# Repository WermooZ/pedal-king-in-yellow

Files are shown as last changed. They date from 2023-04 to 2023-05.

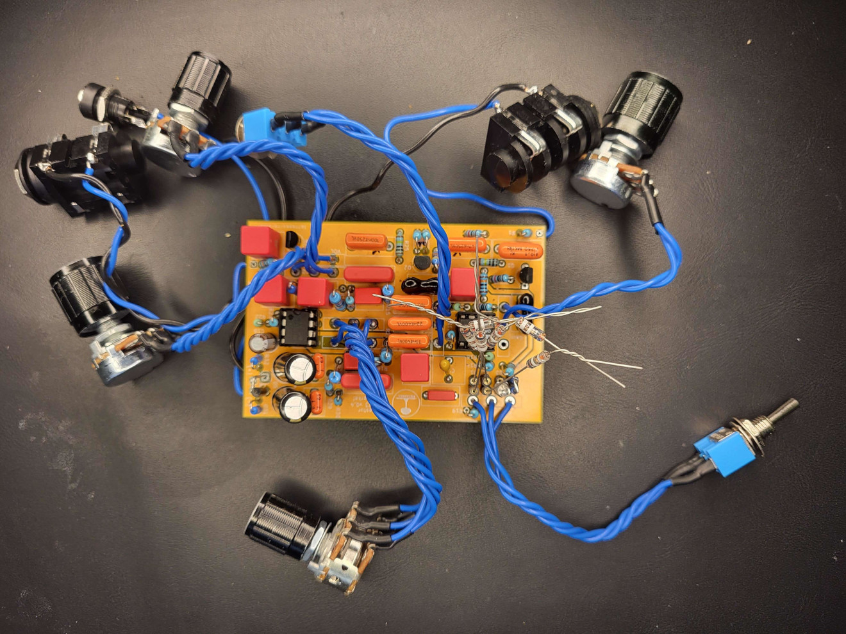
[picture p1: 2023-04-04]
king_in_yelow_assebled.jpg

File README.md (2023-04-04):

# pedal-king-in-yellow

<br />This work is licensed under a <a rel="license" href="http://creativecommons.org/licenses/by-nc-sa/4.0/">Creative Commons Attribution-NonCommercial-ShareAlike 4.0 International License</a>.

Based on the **Exar Super Fuzz SF-02** traced by **VitaliiBobrov** at www.freestompboxes.org

https://www.freestompboxes.org/viewtopic.php?p=293456&hilit=exar#p293456

SF-2 is a fuzz pedal, handmade in Poland in 90s by not existing now Exar Electronix (Janusz Raczyk and Leszek Gruszka).

This version is modified a bit to my taste to improve clarity, tone and noise levels.

Project was assembled and tested - only thing that I messed up is a dual FREQ pot pins -> they are mirrored for one half of pot but it can be fixed by correct wiring so check the schematic first.

Please use Pieczarka logo on pedal enclosure if you want to design own graphics or 'Pieczarka' or 'PCZR' for short.

Project thread on FSB: https://www.freestompboxes.org/viewtopic.php?t=32591

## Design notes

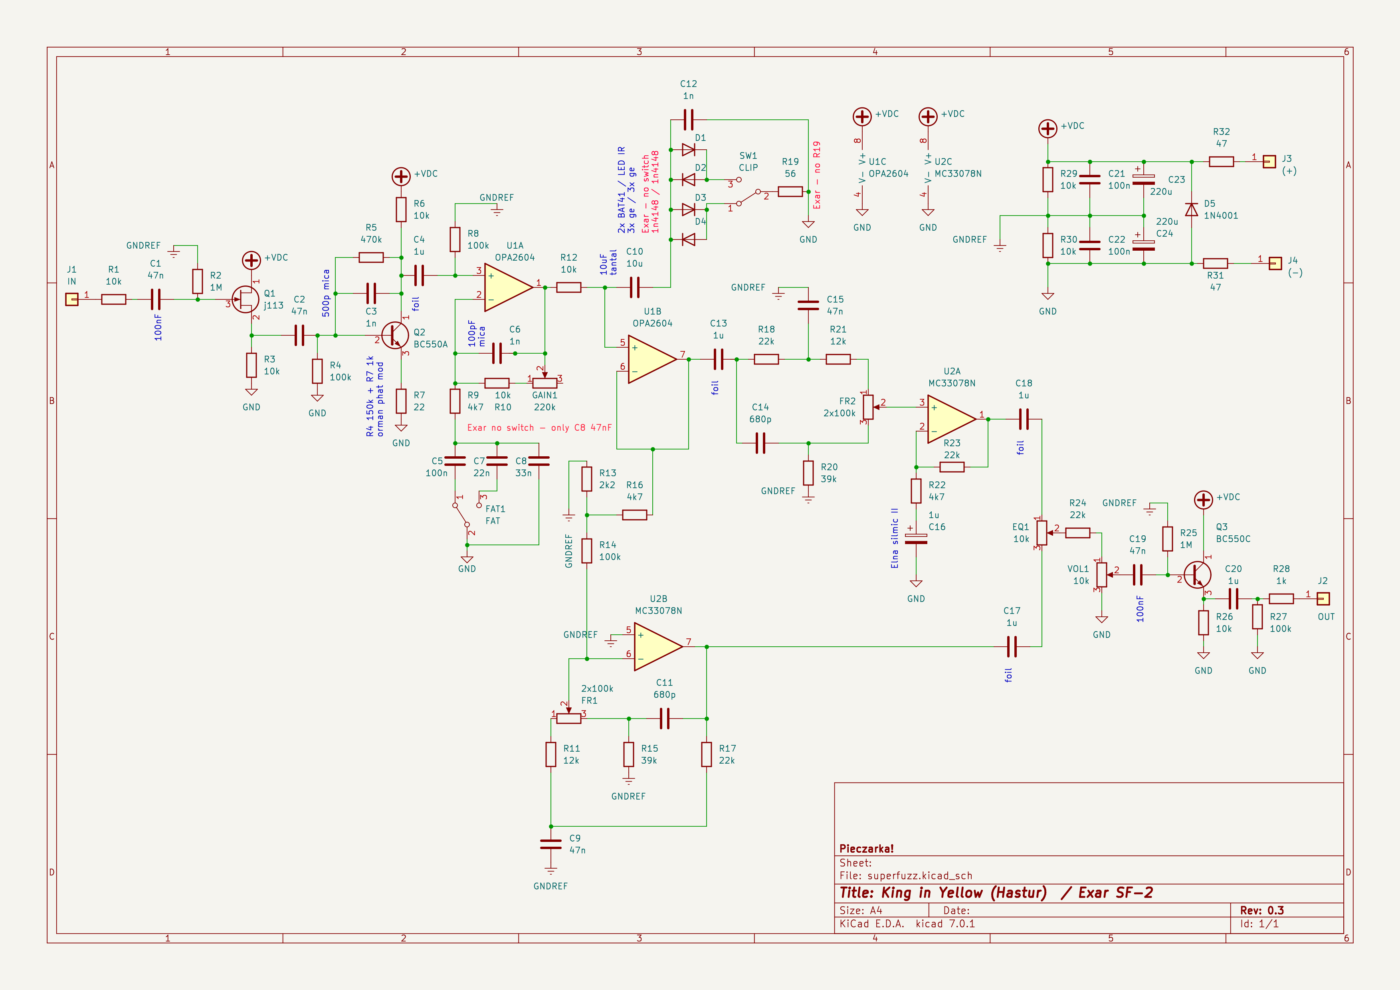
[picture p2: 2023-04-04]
king_in_yellow_schematic.png

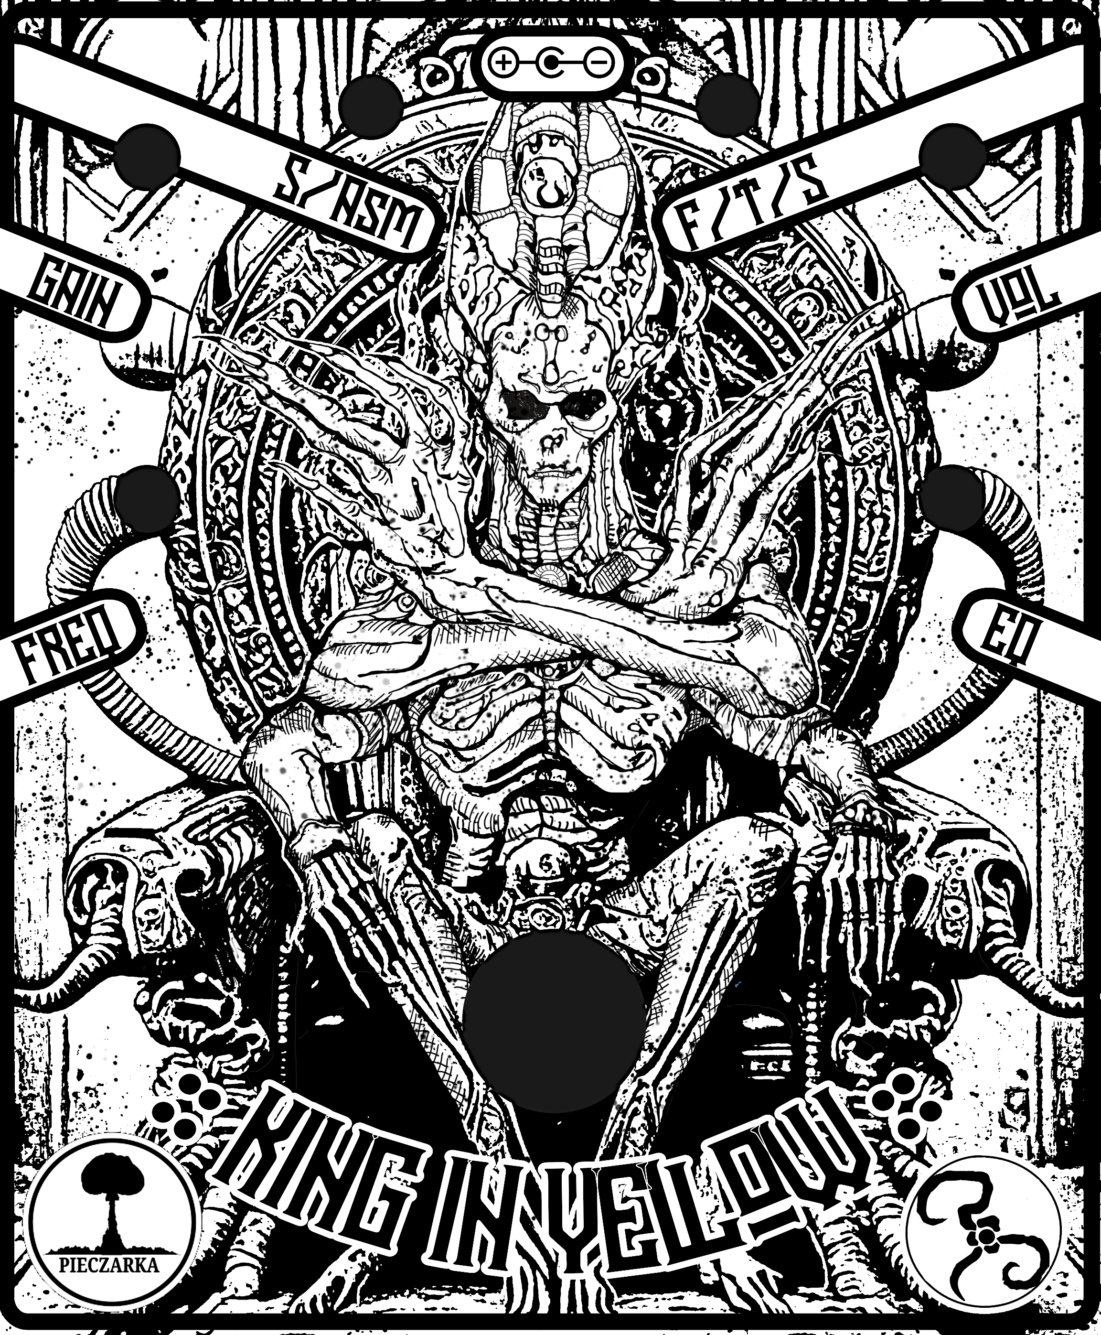
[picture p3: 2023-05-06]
kiy_fx_cover.png

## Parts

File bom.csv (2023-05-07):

Source:
Date: | sob, 28 sty 2023, 21:35:09
Tool: | Eeschema (6.0.10)
Generator: | /usr/share/kicad/plugins/bom_csv_grouped_by_value_with_fp.py
Component Count: | 77
Ref | Qnty | Value | Cmp name | Footprint | Description | Vendor
C1, C2, C9, C15, C19, | 5 | 47n | C | Capacitor_THT:C_Rect_L13.0mm_W5.0mm_P10.00mm_FKS3_FKP3_MKS4 | Unpolarized capacitor
C3, C6, C12, | 3 | 1n | C | Capacitor_THT:C_Rect_L10.0mm_W5.0mm_P5.00mm_P7.50mm | Unpolarized capacitor
C4, C13, C17, C18, C20, | 5 | 1u | C | Capacitor_THT:C_Rect_L7.2mm_W8.5mm_P5.00mm_FKP2_FKP2_MKS2_MKP2 | Unpolarized capacitor
C5, | 1 | 82n | C | Capacitor_THT:C_Rect_L10.0mm_W4.0mm_P7.50mm_MKS4 | Unpolarized capacitor
C7, C8, | 2 | 22n | C | Capacitor_THT:C_Rect_L10.0mm_W4.0mm_P7.50mm_MKS4 | Unpolarized capacitor
C10, | 1 | 10u | C | Capacitor_THT:C_Rect_L7.2mm_W8.5mm_P5.00mm_FKP2_FKP2_MKS2_MKP2 | Unpolarized capacitor
C11, C14, | 2 | 680p | C | Capacitor_THT:C_Rect_L7.2mm_W5.5mm_P5.00mm_FKS2_FKP2_MKS2_MKP2 | Unpolarized capacitor
C16, | 1 | 1u | C_Polarized | Capacitor_THT:CP_Radial_D5.0mm_P2.50mm | Polarized capacitor
C21, C22, | 2 | 100n | C | Capacitor_THT:C_Rect_L7.2mm_W5.5mm_P5.00mm_FKS2_FKP2_MKS2_MKP2 | Unpolarized capacitor
C23, C24, | 2 | 100u | C_Polarized | Capacitor_THT:CP_Radial_D8.0mm_P5.00mm | Polarized capacitor
D1, D2, | 2 | 1N4148 | 1N4148 | Diode_THT:D_DO-35_SOD27_P2.54mm_Vertical_AnodeUp | 100V 0.15A standard switching diode, DO-35
D3, D4, | 2 | Ge | 1N4148 | Diode_THT:D_DO-35_SOD27_P2.54mm_Vertical_AnodeUp | 100V 0.15A standard switching diode, DO-35
D5, | 1 | 1N4001 | 1N4001 | Diode_THT:D_DO-41_SOD81_P3.81mm_Vertical_AnodeUp | 50V 1A General Purpose Rectifier Diode, DO-41
EQ1, | 1 | 10k | R_Potentiometer | varia:potek2 | Potentiometer
FAT1, | 1 | FAT | SW_SPDT | varia:potek2 | Switch, single pole double throw
FR1, | 1 | R_Potentiometer | R_Potentiometer | varia:potek2 | Potentiometer
FR2, | 1 | 100k | R_Potentiometer | varia:potek2 | Potentiometer
GAIN1, | 1 | 220k | R_Potentiometer | varia:potek2 | Potentiometer
J1, | 1 | IN | Conn_01x01 | Connector_Pin:Pin_D0.7mm_L6.5mm_W1.8mm_FlatFork | Generic connector, single row, 01x01, script generated (kicad-library-utils/schlib/autogen/connector/)
J2, | 1 | OUT | Conn_01x01 | Connector_Pin:Pin_D0.7mm_L6.5mm_W1.8mm_FlatFork | Generic connector, single row, 01x01, script generated (kicad-library-utils/schlib/autogen/connector/)
J3, J4, | 2 | Conn_01x01 | Conn_01x01 | Connector_Pin:Pin_D0.7mm_L6.5mm_W1.8mm_FlatFork | Generic connector, single row, 01x01, script generated (kicad-library-utils/schlib/autogen/connector/)
Q1, | 1 | j113 | Q_NJFET_DSG | Package_TO_SOT_THT:TO-92_Inline_Wide | N-JFET transistor, drain/source/gate
Q2, Q3, | 2 | BC550 | BC550 | Package_TO_SOT_THT:TO-92_Inline | 0.1A Ic, 45V Vce, Small Signal NPN Transistor, TO-92
R1, R12, R26, R30, | 4 | 10k | R | Resistor_THT:R_Axial_DIN0204_L3.6mm_D1.6mm_P2.54mm_Vertical | Resistor
R2, R25, | 2 | 1M | R | Resistor_THT:R_Axial_DIN0204_L3.6mm_D1.6mm_P7.62mm_Horizontal | Resistor
R3, R6, R10, R29, | 4 | 10k | R | Resistor_THT:R_Axial_DIN0204_L3.6mm_D1.6mm_P5.08mm_Horizontal | Resistor
R4, R27, | 2 | 100k | R | Resistor_THT:R_Axial_DIN0204_L3.6mm_D1.6mm_P5.08mm_Horizontal | Resistor
R5, | 1 | 470k | R | Resistor_THT:R_Axial_DIN0204_L3.6mm_D1.6mm_P5.08mm_Horizontal | Resistor
R7, | 1 | 22 | R | Resistor_THT:R_Axial_DIN0204_L3.6mm_D1.6mm_P5.08mm_Horizontal | Resistor
R8, | 1 | 100k | R | Resistor_THT:R_Axial_DIN0204_L3.6mm_D1.6mm_P7.62mm_Horizontal | Resistor
R9, | 1 | 4k7 | R | Resistor_THT:R_Axial_DIN0204_L3.6mm_D1.6mm_P5.08mm_Horizontal | Resistor
R11, | 1 | 12k | R | Resistor_THT:R_Axial_DIN0204_L3.6mm_D1.6mm_P5.08mm_Horizontal | Resistor
R13, | 1 | 2k2 | R | Resistor_THT:R_Axial_DIN0204_L3.6mm_D1.6mm_P2.54mm_Vertical | Resistor
R14, | 1 | 100k | R | Resistor_THT:R_Axial_DIN0204_L3.6mm_D1.6mm_P2.54mm_Vertical | Resistor
R15, | 1 | 39k | R | Resistor_THT:R_Axial_DIN0204_L3.6mm_D1.6mm_P2.54mm_Vertical | Resistor
R16, R22, | 2 | 4k7 | R | Resistor_THT:R_Axial_DIN0204_L3.6mm_D1.6mm_P2.54mm_Vertical | Resistor
R17, | 1 | 22k | R | Resistor_THT:R_Axial_DIN0204_L3.6mm_D1.6mm_P5.08mm_Horizontal | Resistor
R18, R23, R24, | 3 | 22k | R | Resistor_THT:R_Axial_DIN0204_L3.6mm_D1.6mm_P2.54mm_Vertical | Resistor
R19, | 1 | 56 | R | Resistor_THT:R_Axial_DIN0204_L3.6mm_D1.6mm_P2.54mm_Vertical | Resistor
R20, | 1 | 39k | R | Resistor_THT:R_Axial_DIN0204_L3.6mm_D1.6mm_P5.08mm_Horizontal | Resistor
R21, | 1 | 12k | R | Resistor_THT:R_Axial_DIN0204_L3.6mm_D1.6mm_P2.54mm_Vertical | Resistor
R28, | 1 | 1k | R | Resistor_THT:R_Axial_DIN0204_L3.6mm_D1.6mm_P5.08mm_Horizontal | Resistor
R31, R32, | 2 | 47 | R | Resistor_THT:R_Axial_DIN0204_L3.6mm_D1.6mm_P2.54mm_Vertical | Resistor
SW1, | 1 | CLIP | SW_SPDT | varia:potek2 | Switch, single pole double throw
U1, U2, | 2 | Opamp_Dual | Opamp_Dual | Package_DIP:DIP-8_W7.62mm_LongPads | Dual operational amplifier
VOL1, | 1 | 10k | R_Potentiometer | varia:potek2 | Potentiometer

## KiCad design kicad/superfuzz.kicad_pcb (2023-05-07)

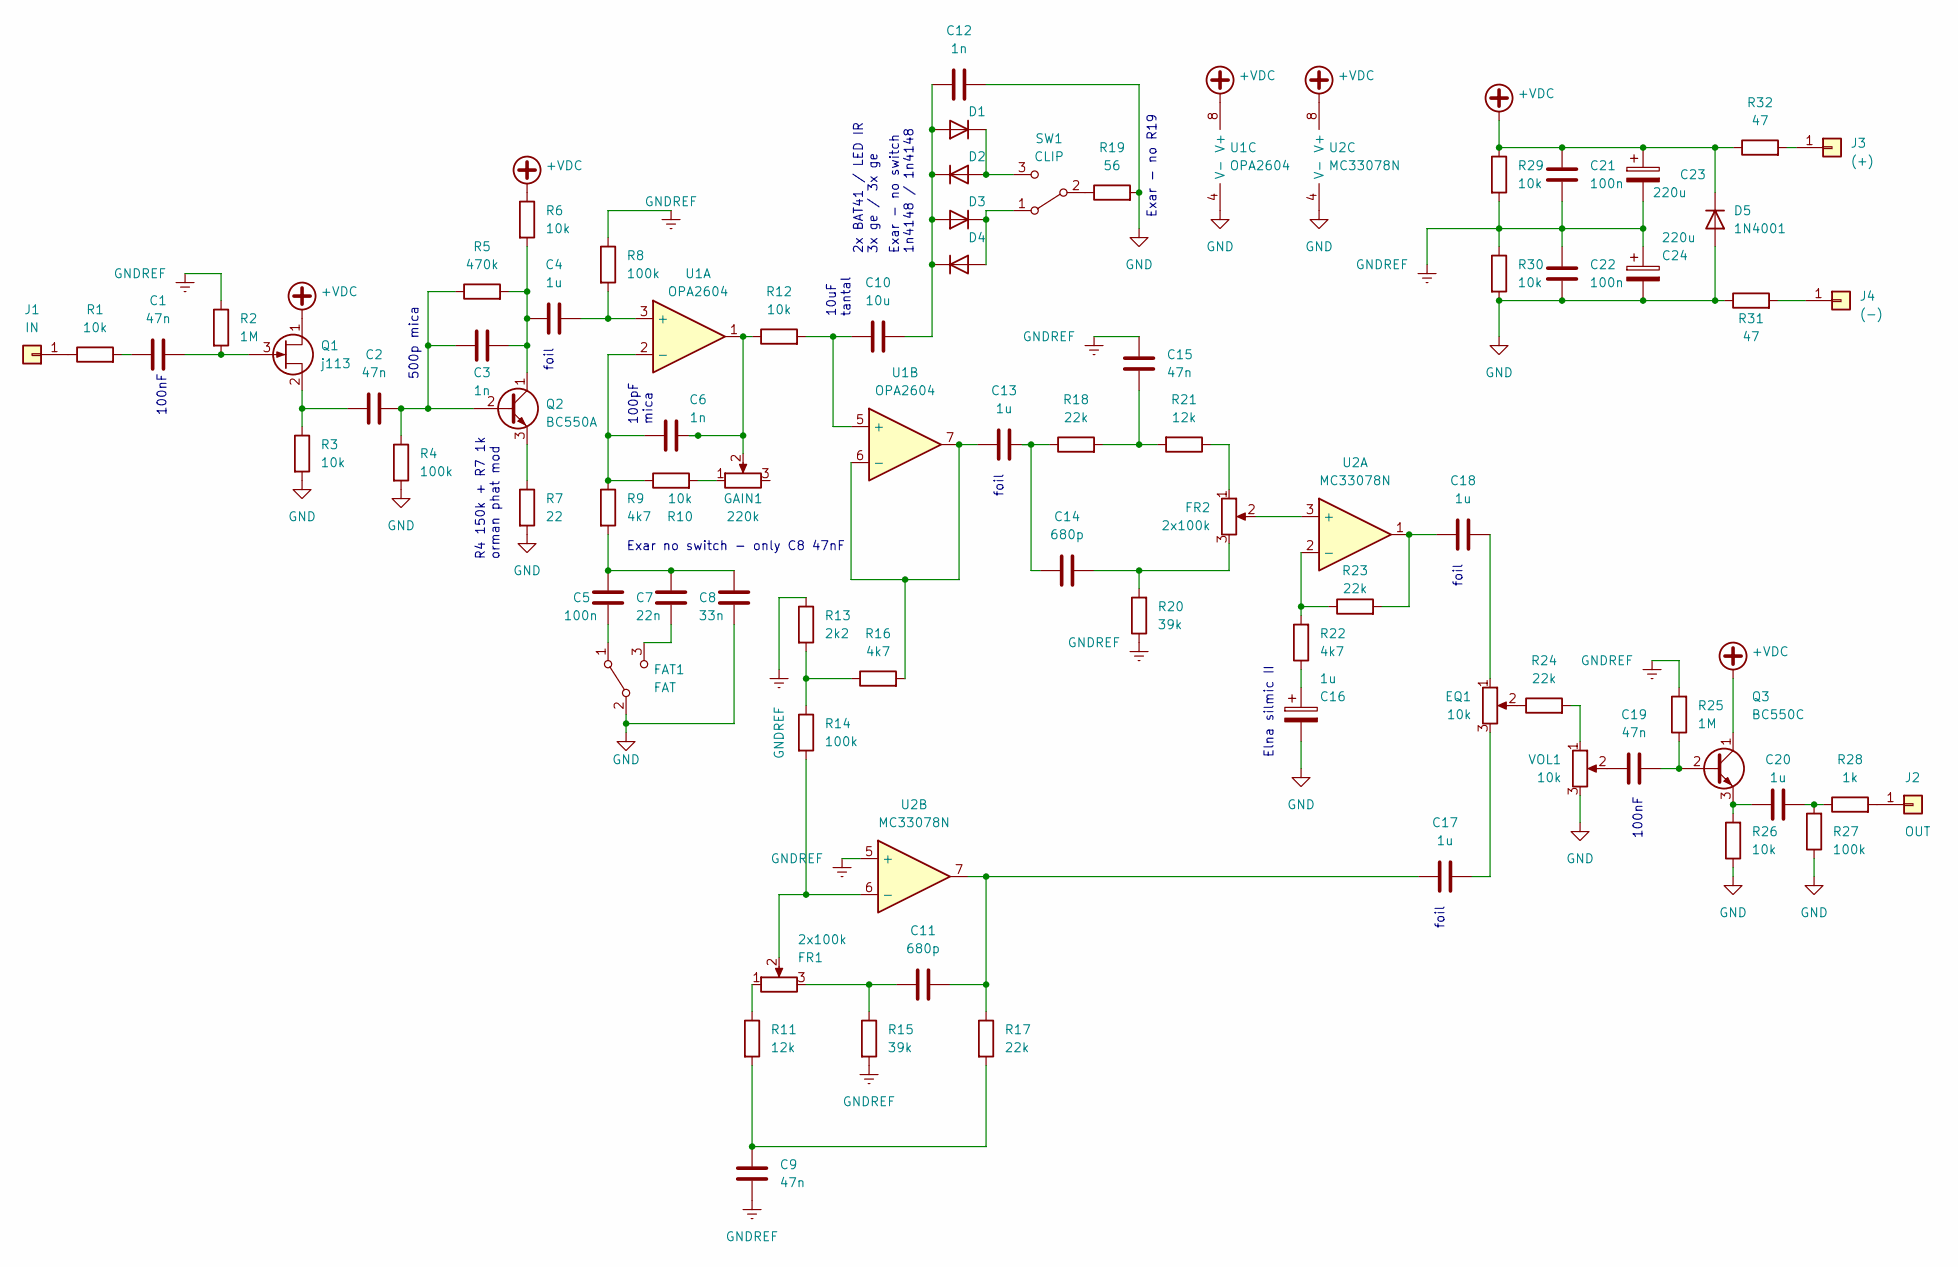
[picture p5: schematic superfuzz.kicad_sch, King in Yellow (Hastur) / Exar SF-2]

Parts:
C1, C2, C9, C15, C19: 47n; C_Rect_L13.0mm_W5.0mm_P10.00mm_FKS3_FKP3_MKS4
C3, C6, C12: 1n; C_Rect_L10.0mm_W5.0mm_P5.00mm_P7.50mm
C4, C13, C17, C18, C20: 1u; C_Rect_L7.2mm_W8.5mm_P5.00mm_FKP2_FKP2_MKS2_MKP2
C5: 100n; C_Rect_L10.0mm_W4.0mm_P7.50mm_MKS4
C7: 22n; C_Rect_L10.0mm_W4.0mm_P7.50mm_MKS4
C8: 33n; C_Rect_L10.0mm_W4.0mm_P7.50mm_MKS4
C10: 10u; C_Rect_L7.2mm_W8.5mm_P5.00mm_FKP2_FKP2_MKS2_MKP2
C11, C14: 680p; C_Rect_L7.2mm_W5.5mm_P5.00mm_FKS2_FKP2_MKS2_MKP2
C16: 1u; CP_Radial_D5.0mm_P2.50mm
C21, C22: 100n; C_Rect_L7.2mm_W5.5mm_P5.00mm_FKS2_FKP2_MKS2_MKP2
C23, C24: 220u; CP_Radial_D8.0mm_P5.00mm
D1, D2: 1N4148; D_DO-35_SOD27_P2.54mm_Vertical_AnodeUp
D3, D4: Ge; D_DO-35_SOD27_P2.54mm_Vertical_AnodeUp
D5: 1N4001; D_DO-41_SOD81_P3.81mm_Vertical_AnodeUp
EQ1: 10k; potek2
FAT1: FAT; potek2
FR1, FR2: 2x100k; potek2
GAIN1: 220k; potek2
J1: IN; Pin_D0.7mm_L6.5mm_W1.8mm_FlatFork
J2: OUT; Pin_D0.7mm_L6.5mm_W1.8mm_FlatFork
J3: (+); Pin_D0.7mm_L6.5mm_W1.8mm_FlatFork
J4: (-); Pin_D0.7mm_L6.5mm_W1.8mm_FlatFork
Q1: j113; TO-92_Inline_Wide
Q2: BC550A; TO-92_Inline
Q3: BC550C; TO-92_Inline
R1, R12, R26, R30: 10k; R_Axial_DIN0204_L3.6mm_D1.6mm_P2.54mm_Vertical
R2, R25: 1M; R_Axial_DIN0204_L3.6mm_D1.6mm_P7.62mm_Horizontal
R3, R6, R10, R29: 10k; R_Axial_DIN0204_L3.6mm_D1.6mm_P5.08mm_Horizontal
R4, R27: 100k; R_Axial_DIN0204_L3.6mm_D1.6mm_P5.08mm_Horizontal
R5: 470k; R_Axial_DIN0204_L3.6mm_D1.6mm_P5.08mm_Horizontal
R7: 22; R_Axial_DIN0204_L3.6mm_D1.6mm_P5.08mm_Horizontal
R8: 100k; R_Axial_DIN0204_L3.6mm_D1.6mm_P7.62mm_Horizontal
R9: 4k7; R_Axial_DIN0204_L3.6mm_D1.6mm_P5.08mm_Horizontal
R11: 12k; R_Axial_DIN0204_L3.6mm_D1.6mm_P5.08mm_Horizontal
R13: 2k2; R_Axial_DIN0204_L3.6mm_D1.6mm_P2.54mm_Vertical
R14: 100k; R_Axial_DIN0204_L3.6mm_D1.6mm_P2.54mm_Vertical
R15: 39k; R_Axial_DIN0204_L3.6mm_D1.6mm_P2.54mm_Vertical
R16, R22: 4k7; R_Axial_DIN0204_L3.6mm_D1.6mm_P2.54mm_Vertical
R17: 22k; R_Axial_DIN0204_L3.6mm_D1.6mm_P5.08mm_Horizontal
R18, R23, R24: 22k; R_Axial_DIN0204_L3.6mm_D1.6mm_P2.54mm_Vertical
R19: 56; R_Axial_DIN0204_L3.6mm_D1.6mm_P2.54mm_Vertical
R20: 39k; R_Axial_DIN0204_L3.6mm_D1.6mm_P5.08mm_Horizontal
R21: 12k; R_Axial_DIN0204_L3.6mm_D1.6mm_P2.54mm_Vertical
R28: 1k; R_Axial_DIN0204_L3.6mm_D1.6mm_P5.08mm_Horizontal
R31, R32: 47; R_Axial_DIN0204_L3.6mm_D1.6mm_P2.54mm_Vertical
SW1: CLIP; potek2
U1: OPA2604; DIP-8_W7.62mm_LongPads
U2: MC33078N; DIP-8_W7.62mm_LongPads
VOL1: 10k; potek2

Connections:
+VDC: C21.1, C23.1, D5.1 (K), Q1.1 (D), Q3.1 (C), R6.1, R29.1, R32.1, U1.8 (V+), U2.8 (V+)
GND: C8.2, C12.2, C16.2, C22.2, C24.2, D5.2 (A), FAT1.2 (B), R3.2, R4.2, R7.2, R19.2, R26.1, R27.1, R30.2, R31.1, U1.4 (V-), U2.4 (V-), VOL1.3
GNDREF: C9.1, C15.2, C21.2, C22.1, C23.2, C24.1, R2.1, R8.1, R13.1, R15.2, R20.1, R25.2, R29.2, R30.1, U2.5 (+)
unnamed: C1.1, R1.2
unnamed: C1.2, Q1.3 (G), R2.2
unnamed: C2.1, Q1.2 (S), R3.1
unnamed: C2.2, C3.1, Q2.2 (B), R4.1, R5.1
unnamed: C3.2, C4.1, Q2.1 (C), R5.2, R6.2
unnamed: C4.2, R8.2, U1.3 (+)
unnamed: C5.1, C7.1, C8.1, R9.2
unnamed: C5.2, FAT1.1 (A)
unnamed: C6.1, R9.1, R10.1, U1.2 (-)
unnamed: C6.2, GAIN1.2, R12.1, U1.1
unnamed: C7.2, FAT1.3 (C)
unnamed: C9.2, R11.2, R17.2
unnamed: C10.1, R12.2, U1.5 (+)
unnamed: C10.2, C12.1, D1.2 (A), D2.1 (K), D3.2 (A), D4.1 (K)
unnamed: C11.1, FR1.3, R15.1
unnamed: C11.2, C17.1, R17.1, U2.7
unnamed: C13.1, R16.2, U1.6 (-), U1.7
unnamed: C13.2, C14.1, R18.1
unnamed: C14.2, FR2.3, R20.2
unnamed: C15.1, R18.2, R21.2
unnamed: C16.1, R22.1
unnamed: C17.2, EQ1.3
unnamed: C18.1, R23.2, U2.1
unnamed: C18.2, EQ1.1
unnamed: C19.1, VOL1.2
unnamed: C19.2, Q3.2 (B), R25.1
unnamed: C20.1, Q3.3 (E), R26.2
unnamed: C20.2, R27.2, R28.1
unnamed: D1.1 (K), D2.2 (A), SW1.3 (C)
unnamed: D3.1 (K), D4.2 (A), SW1.1 (A)
unnamed: EQ1.2, R24.1
unnamed: FR1.1, R11.1
unnamed: FR1.2, R14.2, U2.6 (-)
unnamed: FR2.1, R21.1
unnamed: FR2.2, U2.3 (+)
unnamed: GAIN1.1, R10.2
unnamed: J1.1, R1.1
unnamed: J2.1, R28.2
unnamed: J3.1, R32.2
unnamed: J4.1, R31.2
unnamed: Q2.3 (E), R7.1
unnamed: R13.2, R14.1, R16.1
unnamed: R19.1, SW1.2 (B)
unnamed: R22.2, R23.1, U2.2 (-)
unnamed: R24.2, VOL1.1

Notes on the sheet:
Exar - no switch 1n4148 / 1n4148
100nF
Exar no switch - only C8 47nF
500p mica
foil
10uF tantal
Elna silmic II
Exar - no R19
100pF mica
R4 150k + R7 1k orman phat mod
2x BAT41 / LED IR 3x ge / 3x ge

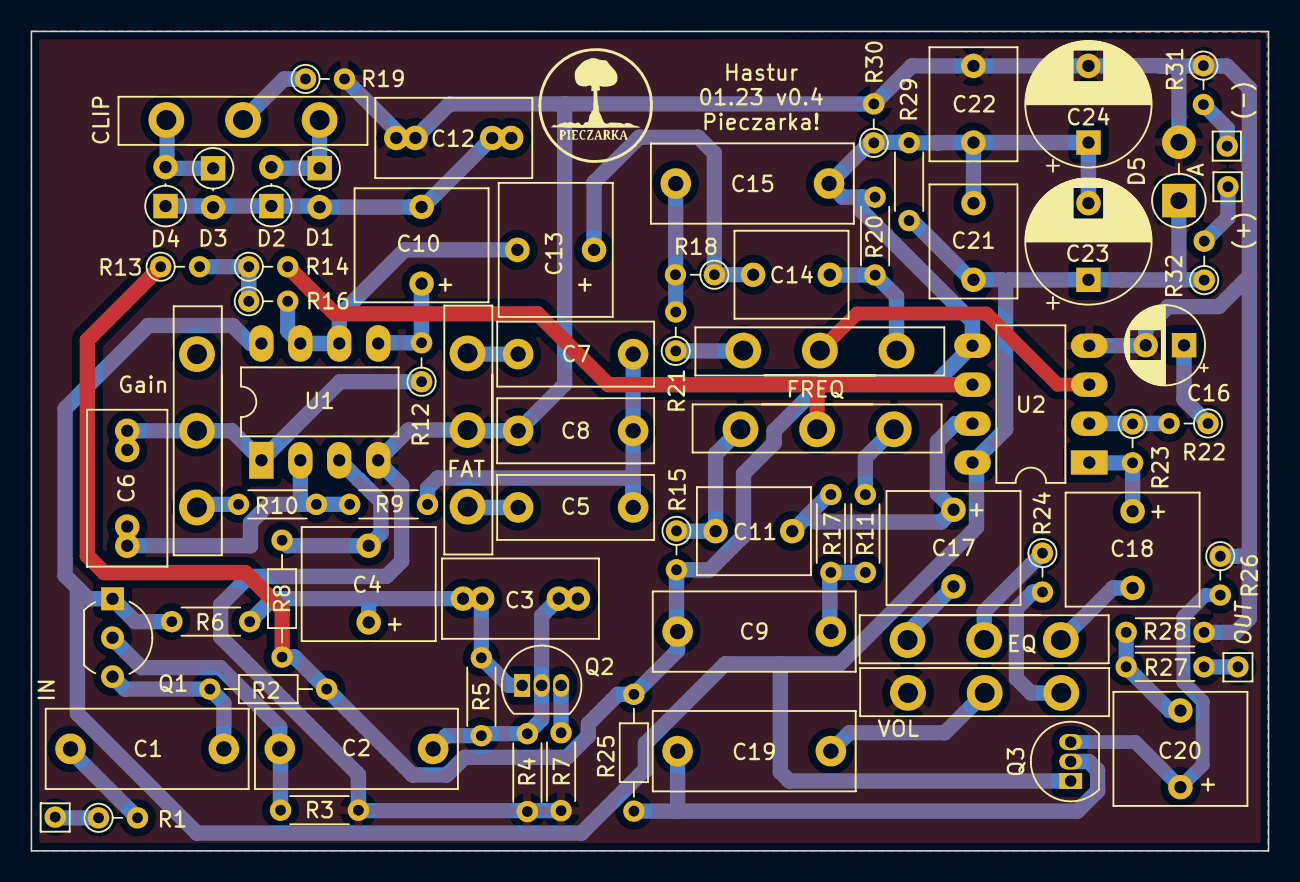
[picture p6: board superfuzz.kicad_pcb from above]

Board: 2 copper layers, 80.7 x 53.5 mm, 77 parts (0 on the bottom side), 48 nets.

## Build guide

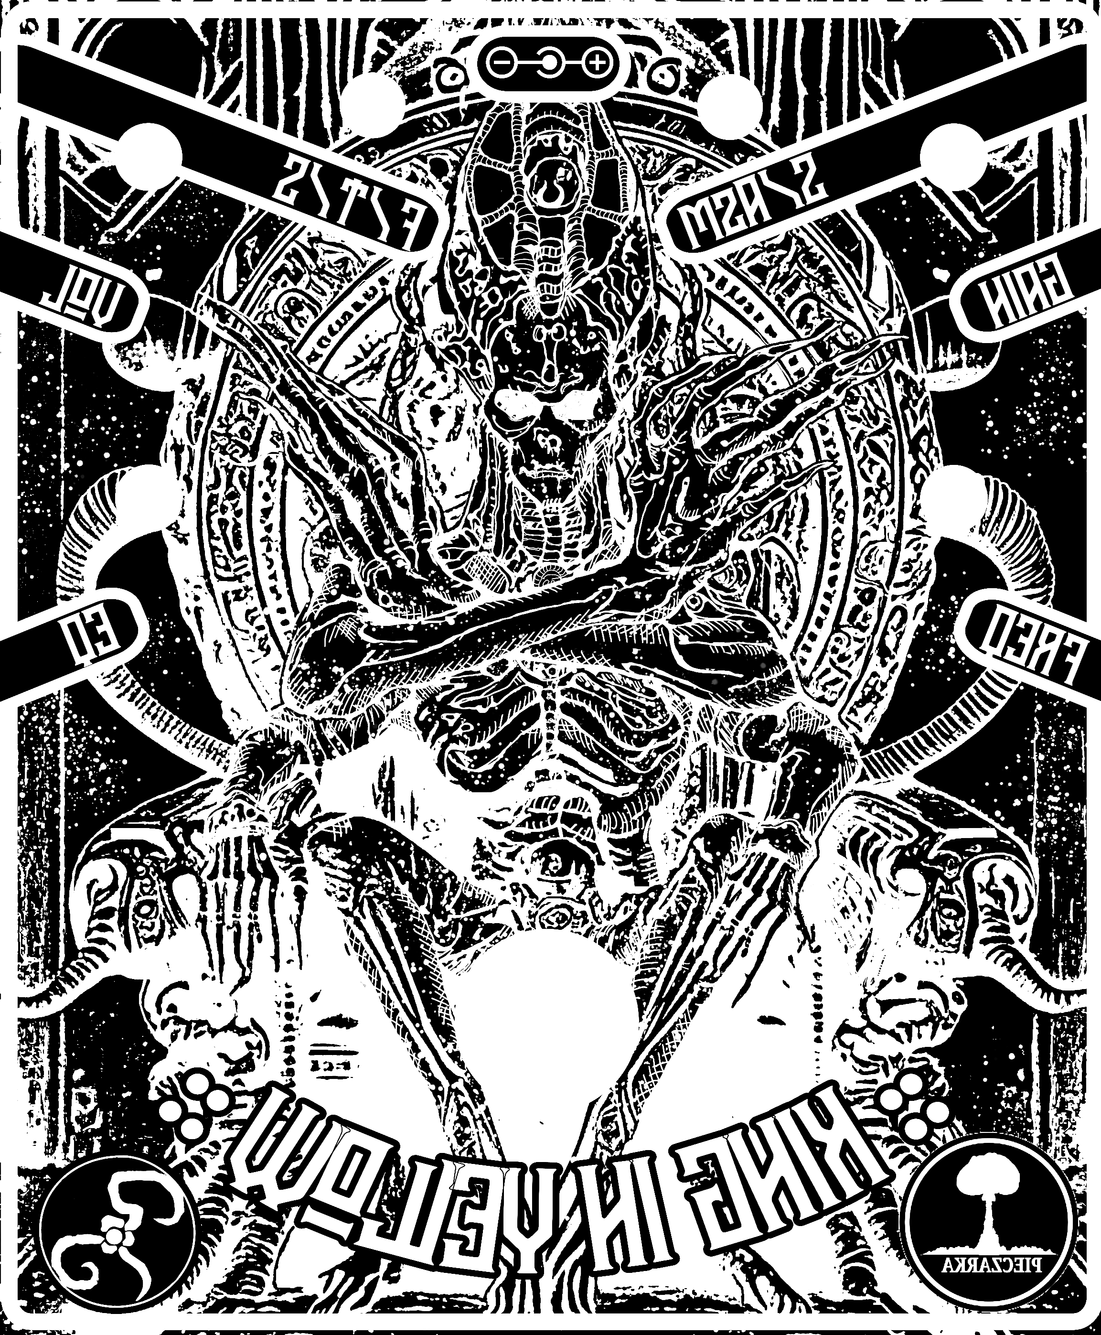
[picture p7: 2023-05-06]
kiy_fx_cover_print.png
